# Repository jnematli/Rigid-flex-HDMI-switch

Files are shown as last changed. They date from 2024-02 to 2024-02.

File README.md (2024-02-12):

# TMD351-Rigid-flex-HDMI-switch
Rigid-Flex HDMI Switch for the Hardware Design course at KU Leuven Campus Group T. The PCB is designed using Autodesk Eagle.

PCB top side:

front

PCB bottom side:

bottom

100 Ohm differential pair:

100ohm_diffpng

PCB build-up:

buildup

## License

All design files in this repository are released under the [GNU General Public License version 3 (GPL-3.0)](LICENSE). They can be freely used for personal projects where this device can be of use.



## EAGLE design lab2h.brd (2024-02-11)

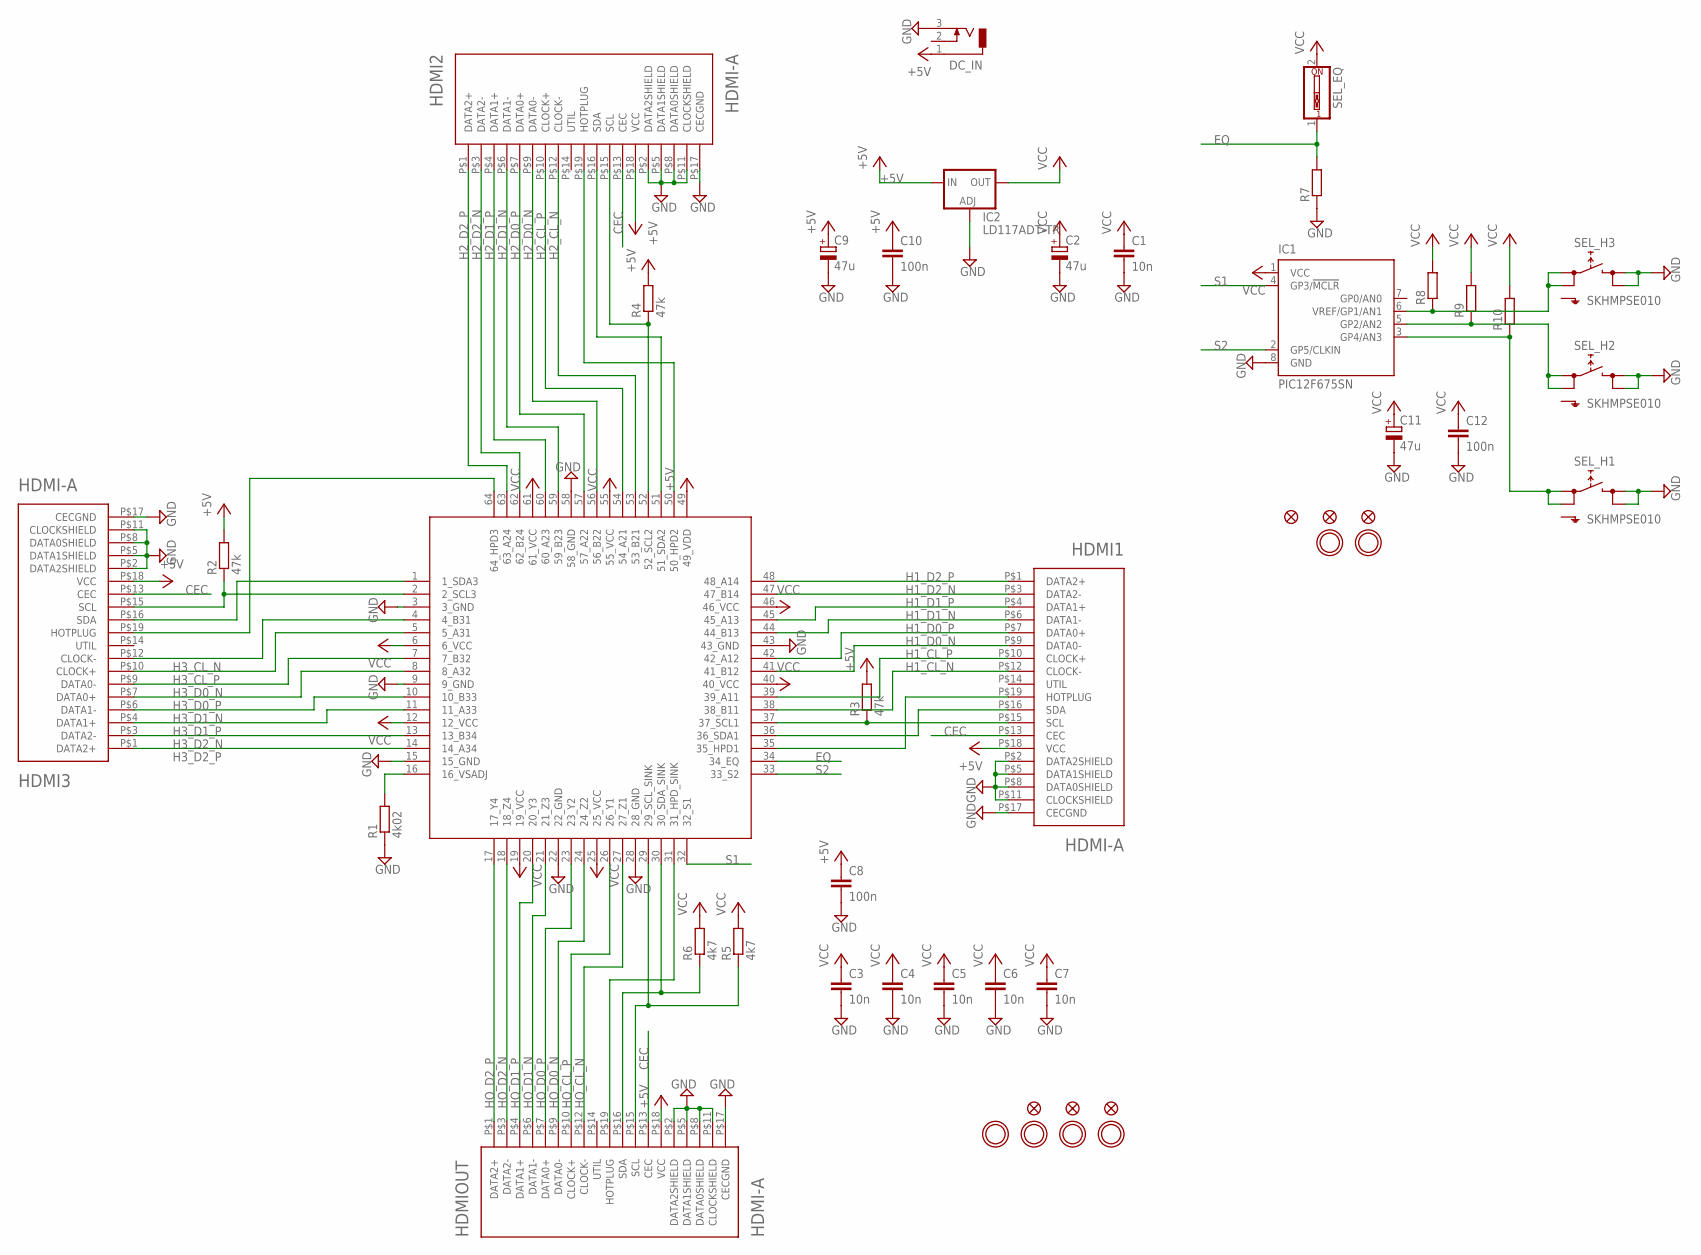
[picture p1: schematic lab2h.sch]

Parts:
C1: 10n; C0402
C2, C9, C11: 47u; SMC_A
C3, C4, C5, C6, C7: 10n; 0402
C8: 100n; 0402
C10, C12: 100n; C0402
DC_IN: DCJ0303
FID1, FID2, FID3, FID4, FID5, FID6: FIDUCIAL""; FIDUCIAL_1MM
HDMI1, HDMI2, HDMI3: HDMI-A; HDMI_A
HDMIOUT: HDMI-A; HDMI_A
IC1: PIC12F675SN; SO-08
IC2: LD117ADT-TR; DPACK
R1: 4k02; 0402
R2, R3, R4: 47k; 0402
R5, R6: 4k7; 0402
R7, R8, R9, R10: R-EU_R0805; R0805
SEL_EQ: SW_DIP-1; EDG-01
SEL_H1, SEL_H2, SEL_H3: SKHMPSE010; SKHMPXE010
U1: TMDS351TQFP64; QFP50P1200X1200X120-64
U$1, U$2, U$31, U$32, U$33, U$34: MOUNTINGHOLE3.0; MOUNTINGHOLE_3.0_PLATED

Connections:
+5V: C8.1, C9.+, C10.1, DC_IN.1, HDMI1.P$18 (VCC), HDMI2.P$18 (VCC), HDMI3.P$18 (VCC), HDMIOUT.P$18 (VCC), IC2.3 (IN), R2.2, R3.2, R4.2, U1.49 (49_VDD)
CEC: HDMI1.P$13 (CEC), HDMI2.P$13 (CEC), HDMI3.P$13 (CEC), HDMIOUT.P$13 (CEC)
EQ: R7.2, SEL_EQ.1, U1.34 (34_EQ)
GND: C1.2, C2.-, C3.2, C4.2, C5.2, C6.2, C7.2, C8.2, C9.-, C10.2, C11.-, C12.2, DC_IN.3, HDMI1.P$2 (DATA2SHIELD), HDMI1.P$5 (DATA1SHIELD), HDMI1.P$8 (DATA0SHIELD), HDMI1.P$11 (CLOCKSHIELD), HDMI1.P$17 (CECGND), HDMI2.P$2 (DATA2SHIELD), HDMI2.P$5 (DATA1SHIELD), HDMI2.P$8 (DATA0SHIELD), HDMI2.P$11 (CLOCKSHIELD), HDMI2.P$17 (CECGND), HDMI3.P$2 (DATA2SHIELD), HDMI3.P$5 (DATA1SHIELD), HDMI3.P$8 (DATA0SHIELD), HDMI3.P$11 (CLOCKSHIELD), HDMI3.P$17 (CECGND), HDMIOUT.P$2 (DATA2SHIELD), HDMIOUT.P$5 (DATA1SHIELD), HDMIOUT.P$8 (DATA0SHIELD), HDMIOUT.P$11 (CLOCKSHIELD), HDMIOUT.P$17 (CECGND), IC1.8 (GND), IC2.1 (ADJ), R1.1, R7.1, SEL_H1.3 (2.1), SEL_H1.4 (2.2), SEL_H2.3 (2.1), SEL_H2.4 (2.2), SEL_H3.3 (2.1), SEL_H3.4 (2.2), U1.3 (3_GND), U1.9 (9_GND), U1.15 (15_GND), U1.22 (22_GND), U1.28 (28_GND), U1.43 (43_GND), U1.58 (58_GND)
H1_CL_N: HDMI1.P$12 (CLOCK-), U1.38 (38_B11)
H1_CL_P: HDMI1.P$10 (CLOCK+), U1.39 (39_A11)
H1_D0_N: HDMI1.P$9 (DATA0-), U1.41 (41_B12)
H1_D0_P: HDMI1.P$7 (DATA0+), U1.42 (42_A12)
H1_D1_N: HDMI1.P$6 (DATA1-), U1.44 (44_B13)
H1_D1_P: HDMI1.P$4 (DATA1+), U1.45 (45_A13)
H1_D2_N: HDMI1.P$3 (DATA2-), U1.47 (47_B14)
H1_D2_P: HDMI1.P$1 (DATA2+), U1.48 (48_A14)
H2_CL_N: HDMI2.P$12 (CLOCK-), U1.53 (53_B21)
H2_CL_P: HDMI2.P$10 (CLOCK+), U1.54 (54_A21)
H2_D0_N: HDMI2.P$9 (DATA0-), U1.56 (56_B22)
H2_D0_P: HDMI2.P$7 (DATA0+), U1.57 (57_A22)
H2_D1_N: HDMI2.P$6 (DATA1-), U1.59 (59_B23)
H2_D1_P: HDMI2.P$4 (DATA1+), U1.60 (60_A23)
H2_D2_N: HDMI2.P$3 (DATA2-), U1.62 (62_B24)
H2_D2_P: HDMI2.P$1 (DATA2+), U1.63 (63_A24)
H3_CL_N: HDMI3.P$12 (CLOCK-), U1.4 (4_B31)
H3_CL_P: HDMI3.P$10 (CLOCK+), U1.5 (5_A31)
H3_D0_N: HDMI3.P$9 (DATA0-), U1.7 (7_B32)
H3_D0_P: HDMI3.P$7 (DATA0+), U1.8 (8_A32)
H3_D1_N: HDMI3.P$6 (DATA1-), U1.10 (10_B33)
H3_D1_P: HDMI3.P$4 (DATA1+), U1.11 (11_A33)
H3_D2_N: HDMI3.P$3 (DATA2-), U1.13 (13_B34)
H3_D2_P: HDMI3.P$1 (DATA2+), U1.14 (14_A34)
HO_CL_N: HDMIOUT.P$12 (CLOCK-), U1.27 (27_Z1)
HO_CL_P: HDMIOUT.P$10 (CLOCK+), U1.26 (26_Y1)
HO_D0_N: HDMIOUT.P$9 (DATA0-), U1.24 (24_Z2)
HO_D0_P: HDMIOUT.P$7 (DATA0+), U1.23 (23_Y2)
HO_D1_N: HDMIOUT.P$6 (DATA1-), U1.21 (21_Z3)
HO_D1_P: HDMIOUT.P$4 (DATA1+), U1.20 (20_Y3)
HO_D2_N: HDMIOUT.P$3 (DATA2-), U1.18 (18_Z4)
HO_D2_P: HDMIOUT.P$1 (DATA2+), U1.17 (17_Y4)
unnamed: HDMI3.P$19 (HOTPLUG), U1.64 (64_HPD3)
unnamed: HDMI2.P$19 (HOTPLUG), U1.50 (50_HPD2)
unnamed: HDMI1.P$19 (HOTPLUG), U1.35 (35_HPD1)
unnamed: HDMIOUT.P$19 (HOTPLUG), U1.31 (31_HPD_SINK)
unnamed: HDMI3.P$16 (SDA), U1.1 (1_SDA3)
unnamed: HDMI3.P$15 (SCL), R2.1, U1.2 (2_SCL3)
unnamed: HDMI2.P$16 (SDA), U1.51 (51_SDA2)
unnamed: HDMI2.P$15 (SCL), R4.1, U1.52 (52_SCL2)
unnamed: HDMI1.P$15 (SCL), R3.1, U1.37 (37_SCL1)
unnamed: HDMI1.P$16 (SDA), U1.36 (36_SDA1)
unnamed: HDMIOUT.P$16 (SDA), R6.1, U1.30 (30_SDA_SINK)
unnamed: HDMIOUT.P$15 (SCL), R5.1, U1.29 (29_SCL_SINK)
unnamed: R1.2, U1.16 (16_VSADJ)
unnamed: IC1.6 (VREF/GP1/AN1), R8.1, SEL_H3.1 (1.1), SEL_H3.2 (1.2)
unnamed: IC1.5 (GP2/AN2), R9.1, SEL_H2.1 (1.1), SEL_H2.2 (1.2)
unnamed: IC1.3 (GP4/AN3), R10.1, SEL_H1.1 (1.1), SEL_H1.2 (1.2)
S1: IC1.4 (GP3/!MCLR), U1.32 (32_S1)
S2: IC1.2 (GP5/CLKIN), U1.33 (33_S2)
VCC: C1.1, C2.+, C3.1, C4.1, C5.1, C6.1, C7.1, C11.+, C12.1, IC1.1 (VCC), IC2.4 (OUT), R5.2, R6.2, R8.2, R9.2, R10.2, SEL_EQ.2, U1.6 (6_VCC), U1.12 (12_VCC), U1.19 (19_VCC), U1.25 (25_VCC), U1.40 (40_VCC), U1.46 (46_VCC), U1.55 (55_VCC), U1.61 (61_VCC)

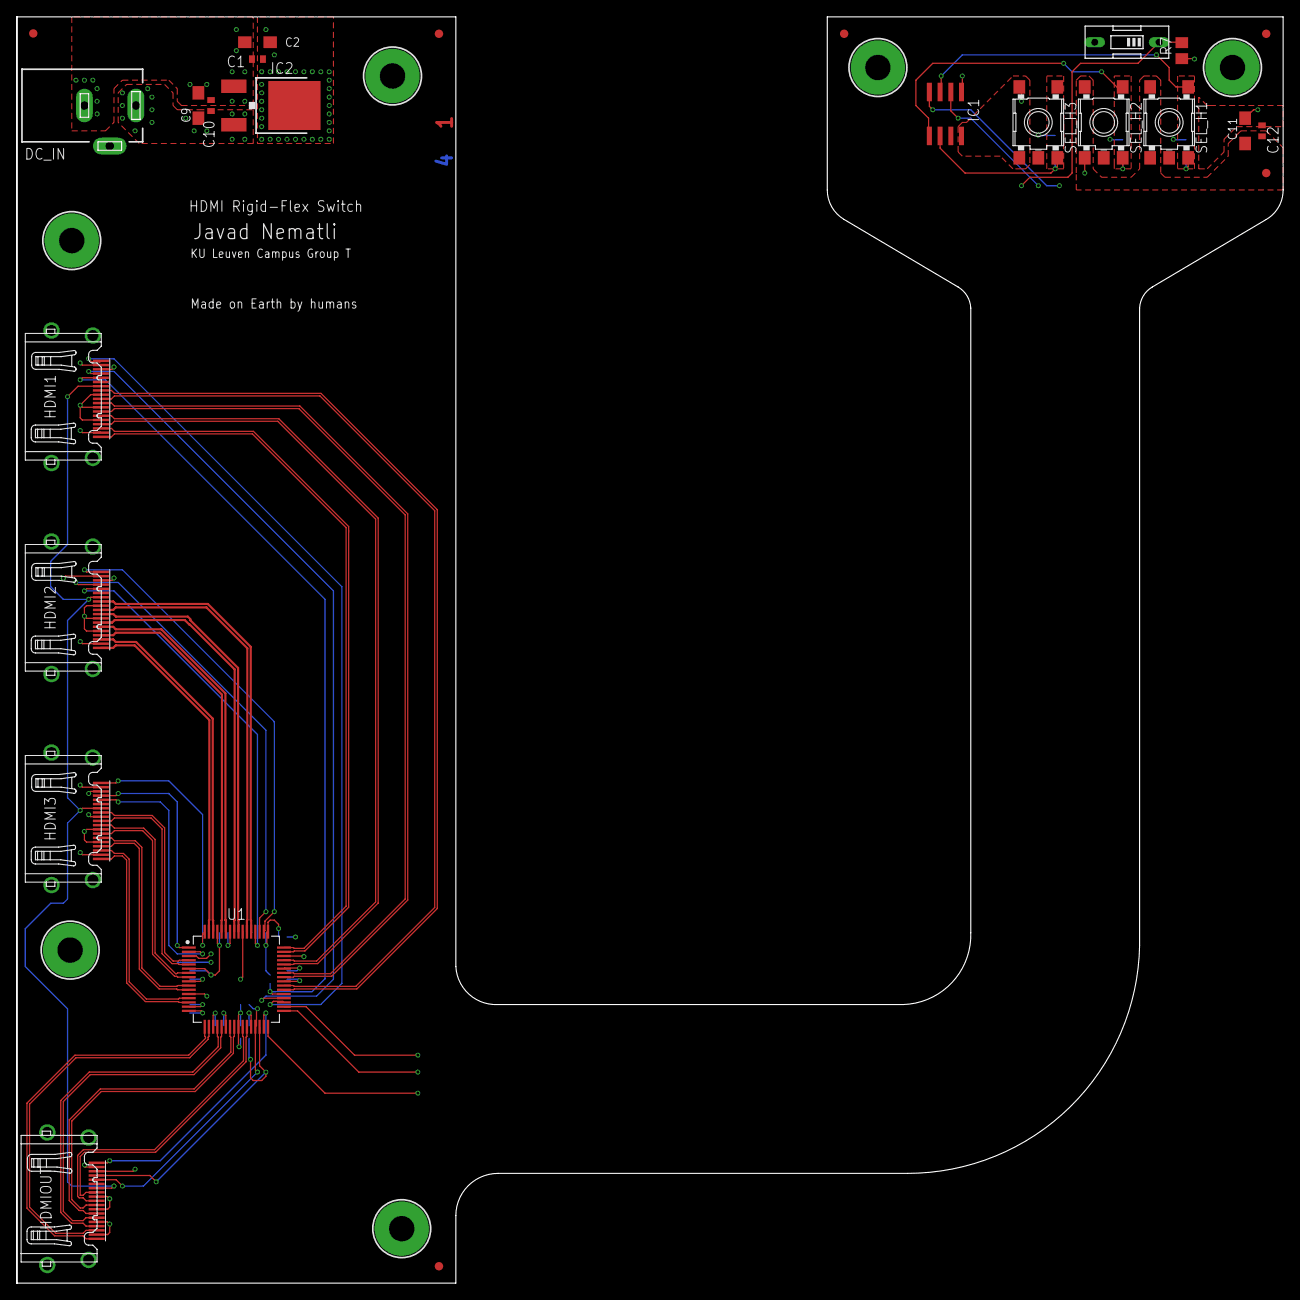
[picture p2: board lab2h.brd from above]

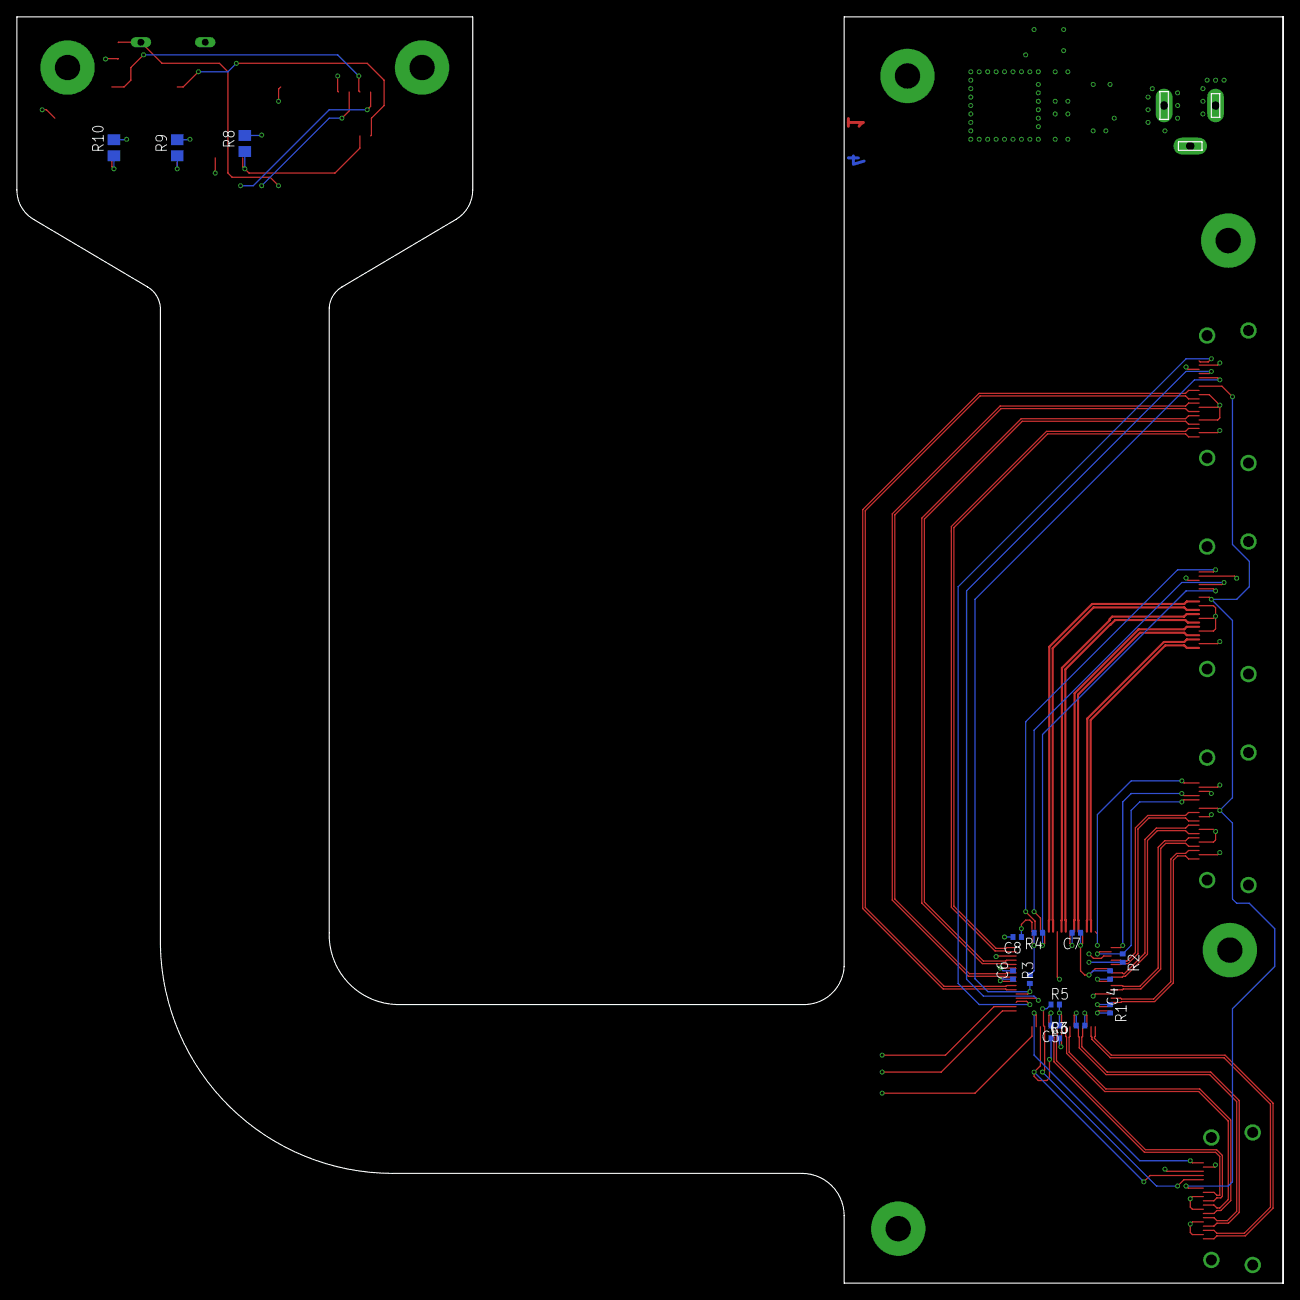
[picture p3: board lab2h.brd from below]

Board: 4 copper layers, 150.0 x 150.0 mm, 46 parts (15 on the bottom side), 55 nets.

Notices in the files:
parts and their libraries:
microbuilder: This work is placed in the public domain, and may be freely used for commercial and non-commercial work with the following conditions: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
